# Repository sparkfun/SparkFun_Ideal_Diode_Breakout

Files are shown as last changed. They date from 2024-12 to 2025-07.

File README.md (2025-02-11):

SparkFun Ideal Diode Breakout
========================================

SparkFun Ideal Diode Breakout (https://www.sparkfun.com/products/27925)

[*SparkFun Ideal Diode Breakout (COM-27925)*](https://www.sparkfun.com/products/27925)




Keep your project powered up during power supply hot-swaps with the SparkFun Ideal Diode Breakout. This compact (15.2mm x 12.7mm) breakout board features four channels and ground connections, providing reliable one-way voltage control. Ideal diodes minimize forward voltage drop, internal power dissipation, and reverse DC leakage current, making them perfect for dynamic power selection and switchover, over-voltage protection, and projects requiring stable power input.

This breakout boasts impressive performance with a typical forward voltage drop as low as 8mV at 0.1A (20V input) and 62mV at 1A (20V input), ensuring efficient power delivery. For higher current applications, the forward voltage drop is typically 275mV at 4A (20V input). The typical on-resistance ranges from 69mΩ (20V, 4A) to 260mΩ (1.8V, 0.1A), depending on the input voltage and current. Reverse leakage current is minimal, ranging from -50µA to -560µA depending on reverse voltage and again on the input voltage.

Repository Contents
-------------------

* **/Hardware** - KiCAD design files (.brd, .sch)
* **/Documents** - Files related to the hardware on the board
* **/docs** - Hookup guide files

Documentation
--------------
* **[Hookup Guide](https://docs.sparkfun.com/SparkFun_Ideal_Diode_Breakout)** - Basic hookup guide for the SparkFun Ideal Diode Breakout

License Information
-------------------

This product is _**open source**_! 

Please review the LICENSE.md file for license information. 

If you have any questions or concerns on licensing, please contact technical support on our [SparkFun forums](https://forum.sparkfun.com/viewforum.php?f=152).

Distributed as-is; no warranty is given.

- Your friends at SparkFun.

_<COLLABORATION CREDIT>_

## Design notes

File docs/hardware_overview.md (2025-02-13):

---
icon: material/cog
---
## Overview

The SparkFun Ideal Diode Breakout uses four MOSFET P-CH SOT23 chips and four transistor arrays to provide four inputs and four outputs as well as a single common ground.  

## Typical Characteristics

We've gathered some data here to give you an idea of the typical characteristics and behavior of the diodes on this breakout. 

<div style="text-align: center;">
    <table>
        <tr>
            <td style="text-align: Left; border: solid 1px #cccccc;">Max forward current: 4.2A
            </td>
            <td style="text-align: center; border: solid 1px #cccccc;">This is based on the MOSFET current rating, which depends on various factors. Higher input voltge and higher forward current result in higher gate voltage, which reduces the drain-source resistance, which reduces heat dissipation, allowing for higher current before failure of MOSFET. 4.2A continuous should be achievable with VIN=5V and 25C ambient temperature. See MOSFET dtasheet for more details.
            </td>
        </tr>
        <tr>        
            <td style="text-align: Left; border: solid 1px #cccccc;">Breakdown voltage: -9.3V
            </td>
            <td style="text-align: center; border: solid 1px #cccccc;">The base-emitter path of the BJTs is effectively a diode, which exhibits breakdown behavior with a large reverse voltage. The BJT datasheet rates this as byeond -5V, however testing shows it occurs closer to -9V. The -9.3V rating of the ideal diode circuit includes the forward voltage drop of the other BJT's base-emitter path. Larger reverse voltages can be tolerated, however this can lead to significant heat and eventually failure of the BJT, so larger reverse voltages (<-10V) should only be applied briefly.
            </td>
        </tr>
        <tr>            
            <td style="text-align: Left; border: solid 1px #cccccc;">Max input voltage: 20V
            </td>   
            <td style="text-align: center; border: solid 1px #cccccc;">The MOSFET gate is pulled down when the ideal diode circuit operates in the forward region. This behavior is analog, so a higher input voltage and higher forward current brings the gate voltage closer to GND. The MOSFET datasheet only rates the gate-source voltage at 8V max, however testing has shown it can tolerate up to 20V before immediate failure, which is the motivation for the max input voltage rating of the ideal diode circuit. Extended operation with the gate-source voltage beyond 8V may result in degradation or failure.
            </td>
        </tr>
        <tr>            
            <td style="text-align: Left; border: solid 1px #cccccc;">Min input voltage: 1V-1.8V
            </td>   
            <td style="text-align: center; border: solid 1px #cccccc;">The threshold gate-source voltage of the MOSFET is typically 0.5V-0.9V according to the datasheet. The gate can only go as low as GND, which is the motivation for the 1V minimum. However the gate does not get pulled all the way to GND, so a low input voltage (1.8V and lower) results in a higher drain-source resistance. This can result in a higher forward voltage drop, and significantly more heating of the MOSFET with high current. Extended operation at low input voltage and high current could cause the MOSFET to fail.
            </td>
        </tr>
    </table>
</div>

Some initial testing gives us the following data. We've listed some of the basics; full information, including raw data and further graphs can be [found here](https://docs.google.com/spreadsheets/d/10VnG3ES4PncXXFxEykBQ4V_JlhlVdun92eYzSfNOVCA/edit?usp=sharing).

<figure markdown>
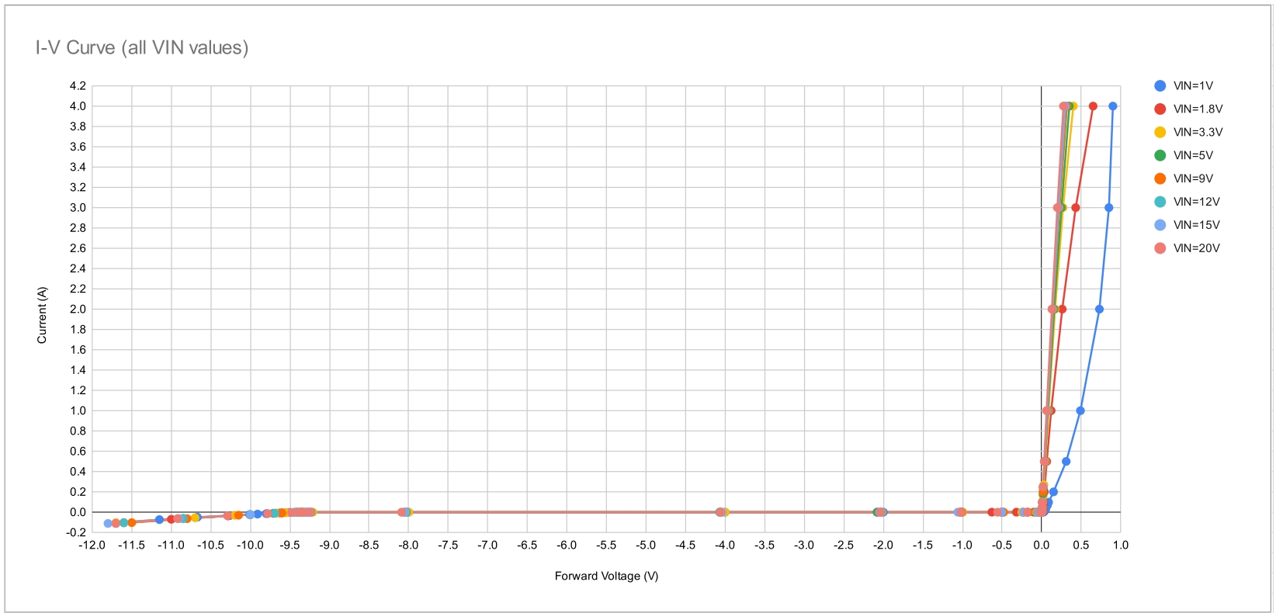
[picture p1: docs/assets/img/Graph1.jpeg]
Functional Graph 1

<figcaption markdown>Overall Current/Voltage Curve (Linear Scale)</figcaption>
</figure>

<figure markdown>
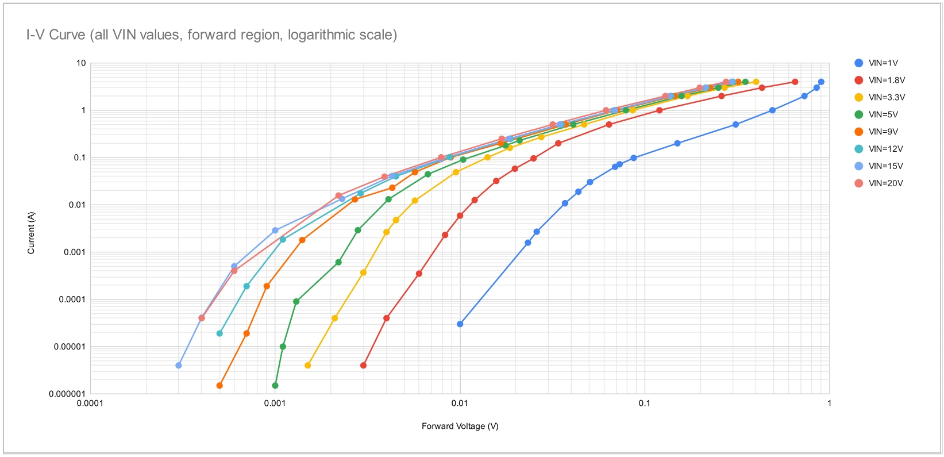
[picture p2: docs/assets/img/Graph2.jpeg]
Functional Graph 2

<figcaption markdown>Positive Region (Logarithmic Scale)</figcaption>
</figure>

<figure markdown>
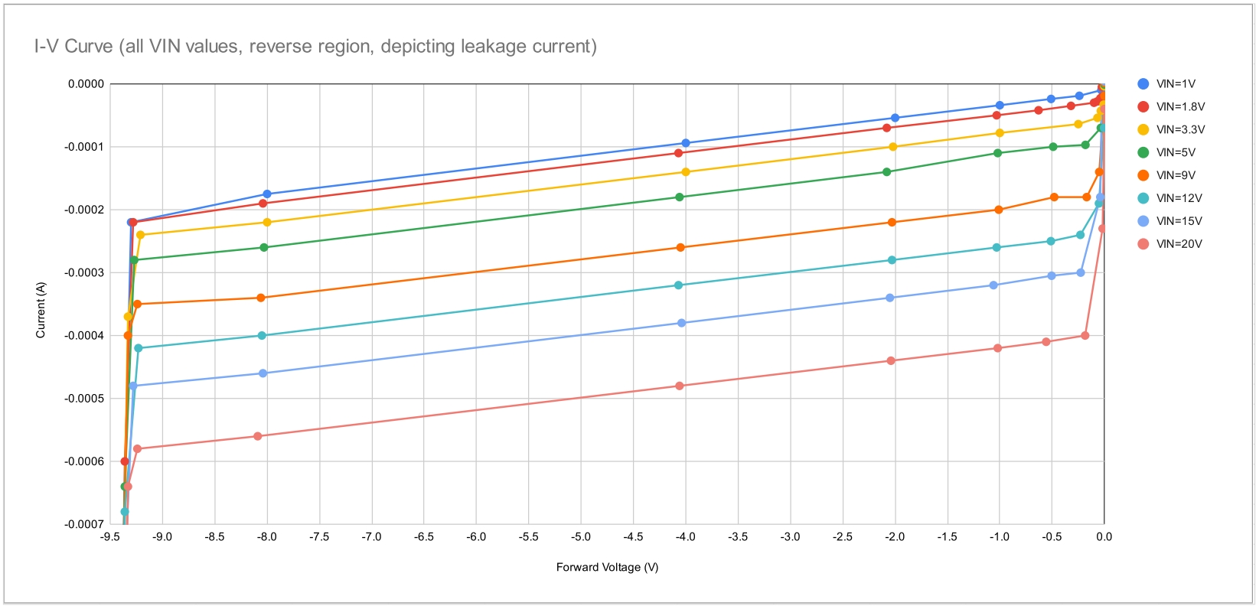
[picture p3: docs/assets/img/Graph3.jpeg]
Functional Graph 3

<figcaption markdown>Leakage Current</figcaption>
</figure>

<figure markdown>
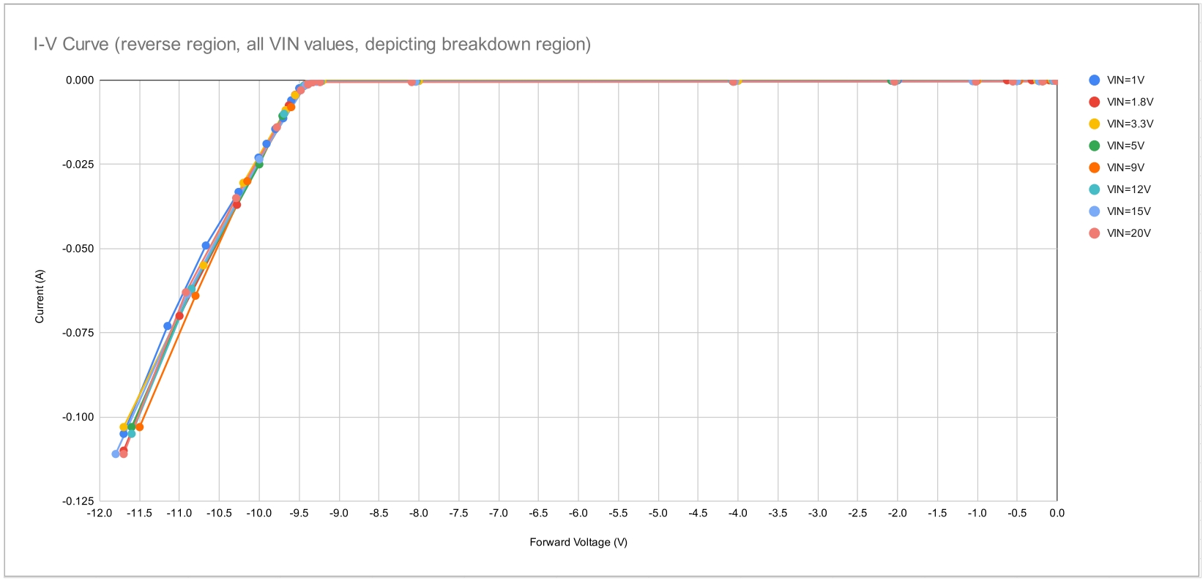
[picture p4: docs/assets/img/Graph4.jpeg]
Functional Graph 4

<figcaption markdown>Breakdown Voltage Behavior</figcaption>
</figure>

### 3D Model

A 3D model of the board and components was exported to a STEP file using KiCad.

<script type="module" src="https://ajax.googleapis.com/ajax/libs/model-viewer/3.5.0/model-viewer.min.js"></script>

<center>
    <model-viewer src="../assets/3d_model/SparkFun_Ideal_Diode_Breakout_3d_model.glb" camera-controls poster="../assets/3d_model/SparkFun_Ideal_Diode_Breakout_3d_model.png" environment-image="legacy" shadow-intensity="1.58" exposure="0.64" shadow-softness="0.24" tone-mapping="neutral" camera-orbit="-46.67deg 57.14deg 153.3m" field-of-view="30deg" style="width: 750px; height: 500px;">
    </model-viewer>
</center>
<br />
<div style="text-align: center">
    <a href="../assets/3d_model/SparkFun_Ideal_Diode_Breakout_3d_model.step" target="stp_file" class="md-button">Click Here for the STEP File</a>
</div>

### Board Dimensions

The board measures 15.2mm x 12.7mm(0.5 x 0.6 inches). 

<figure markdown>
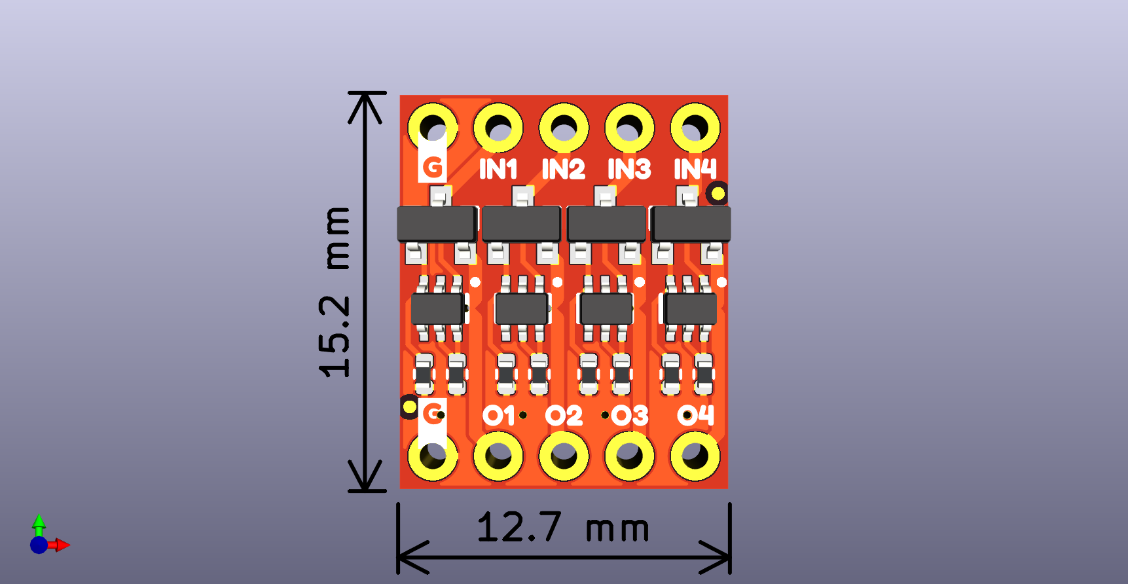
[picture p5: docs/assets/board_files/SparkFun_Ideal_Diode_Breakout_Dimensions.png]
Board Dimensions are 15.2mm by 12.7mm

<figcaption markdown>Board Dimensions</figcaption>
</figure>

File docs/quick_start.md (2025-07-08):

---
icon: material/run-fast
hide: toc
---

<div class="grid cards desc" markdown>

-    <a href="https://www.sparkfun.com/products/27925">
    **SparkFun Ideal Diode Breakout**<br>
    **SKU:** COM-27925

    ---

    <figure markdown>
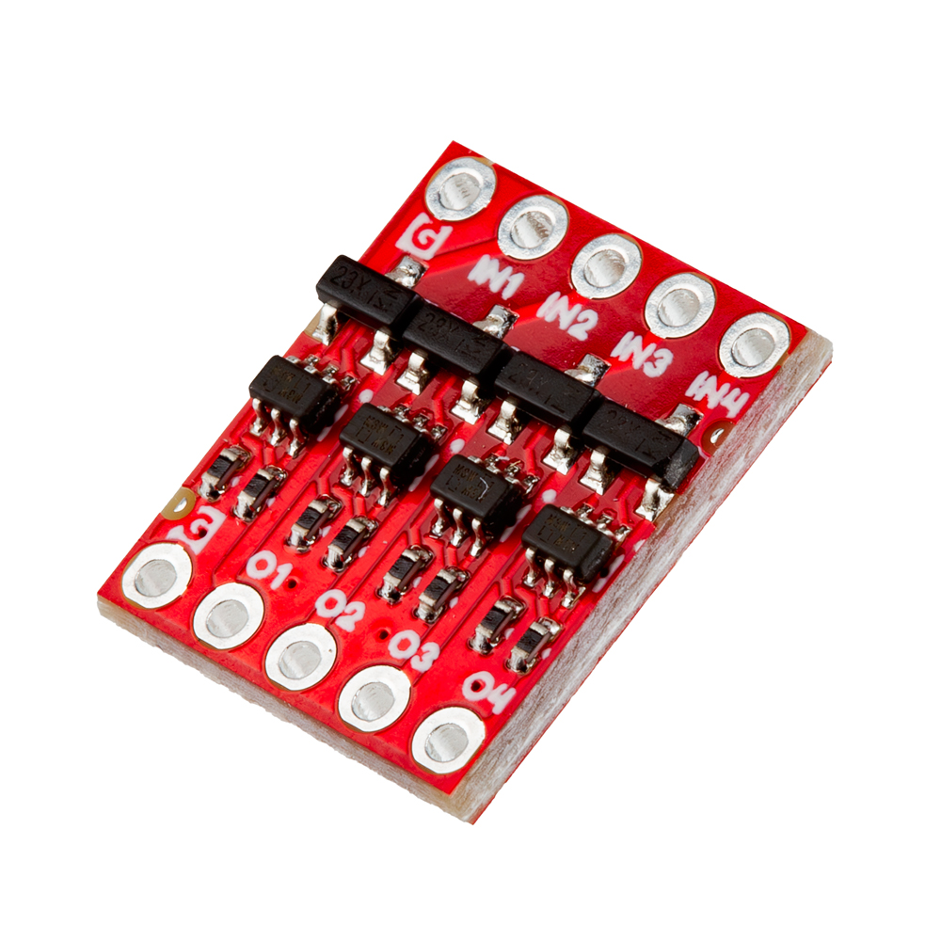
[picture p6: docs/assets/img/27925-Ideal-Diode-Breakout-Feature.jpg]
Product Thumbnail
    
    </figure></a>

-    Keep your project powered up during power supply hot-swaps with the SparkFun Ideal Diode Breakout. This compact (15.2mm x 12.7mm) breakout board features four channels and ground connections, providing reliable one-way voltage control. Ideal diodes minimize forward voltage drop, internal power dissipation, and reverse DC leakage current, making them perfect for dynamic power selection and switchover, over-voltage protection, and projects requiring stable power input.

    This breakout boasts impressive performance with a typical forward voltage drop as low as 8mV at 0.1A (20V input) and 62mV at 1A (20V input), ensuring efficient power delivery. For higher current applications, the forward voltage drop is typically 275mV at 4A (20V input). The typical on-resistance ranges from 69mΩ (20V, 4A) to 260mΩ (1.8V, 0.1A), depending on the input voltage and current. Reverse leakage current is minimal, ranging from -50µA to -560µA depending on reverse voltage and again on the input voltage.

    <center>
    [Purchase from SparkFun :fontawesome-solid-cart-plus:{ .heart }](https://www.sparkfun.com/products/27925){ .md-button .md-button--primary }
    </center>

</div>

## Hooking Up the Breakout

Hooking up the SparkFun Ideal Diode Breakout is fairly straightforward. Power inputs go through two separate input circuits but have a common ground. A quick example shows consistent current being supplied to the board from two separate power supplies. Note that as one power supply decreases, the other draw increases to provide consistent voltage: 

<figure markdown>
Hot Swapping Power Supply
<figcaption markdown>Hot Swapping a Power Supply to a Motor</figcaption>
</figure>

Hookup looks something like the following: 

<figure markdown>
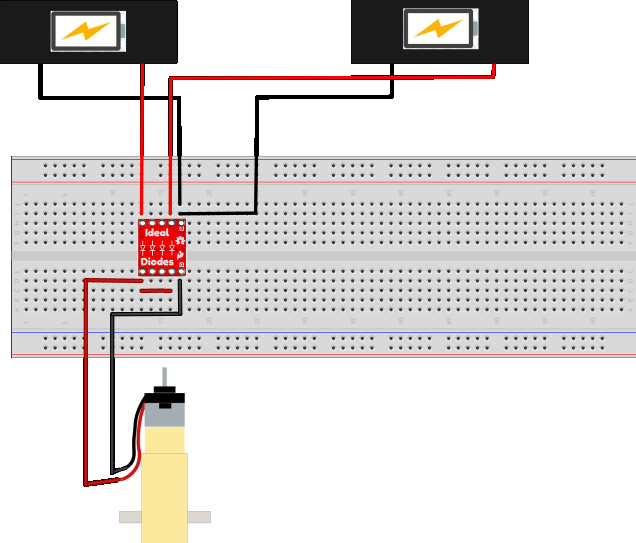
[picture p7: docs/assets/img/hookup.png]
Hot Swapping Power Supply

<figcaption markdown>Hot Swapping a Power Supply to a Motor</figcaption>
</figure>

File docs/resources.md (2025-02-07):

For more information, check out the resources below:

* [Ideal Diode Characteristics (PDF)](../assets/board_files/IdealDiodeCharacteristics-Graphs.pdf)
* [Schematic (PDF)](../assets/board_files/27925_SparkFun_Ideal_Diode_Breakout_Schematic.pdf)
* [KiCad Files (ZIP)](../assets/board_files/27925_SparkFun_Ideal_Diode_Breakout_KiCADFiles.zip)
* [3D Model (STEP)](../assets/3d_model/SparkFun_Ideal_Diode_Breakout_3d_model.step)
* [Board Dimensions (PNG)](../assets/board_files/SparkFun_Ideal_Diode_Breakout_Dimensions.png)
* [GitHub Hardware Repo](https://github.com/sparkfun/SparkFun_Ideal_Diode_Breakout)

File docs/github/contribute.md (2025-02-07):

# Contribute: Help Fix our Mistake!
Spot something wrong? Feel free to contribute our open-source design and documentation. 

## Improve our Documentation
All of this documentation can be modified by you! Please help us make it better.

* These pages are contained in the [`docs` folder of the SparkFun Ideal Diode Breakout repository](https://github.com/sparkfun/SparkFun_Ideal_Diode_Breakout/tree/main/docs).

### Submit a Correction
1. Fork this repo
2. Add your corrections or improvements to the markdown file
3. File a pull request with your changes, and enjoy making the ~~words~~ ~~worlds~~ world a better place.
    * Once received, the documentation specialist will automatically be notified.
    * We will review your suggested improvements to make sure they are correct and fit within our documentation standards.

## Improve our Hardware Design
All of our designs are open-source! Please help us make it better.

* Our board design files are contained in the [`Hardware` folder of the SparkFun Ideal Diode Breakout repository](https://github.com/sparkfun/SparkFun_Ideal_Diode_Breakout/tree/main/Hardware).

### Submit a Design Improvement
1. Fork this repo
2. Add your design improvements
3. File a pull request with your changes, and enjoy making the ~~words~~ ~~worlds~~ world a better place.
    * Once received, the engineer in charge of the original design will automatically be notified.
    * We will review your suggested improvements, if they are within our board design standards and meet our product design requirements, we will flag these changes for our next board revision. *(Please note, that even if your suggestion is accepted, these changes may not be immediate. We may have to cycle through our current product inventory first.)*

## Contributors
Let's provided some recognition to the contributors for this project!

GitHub Contributors Image
<br>


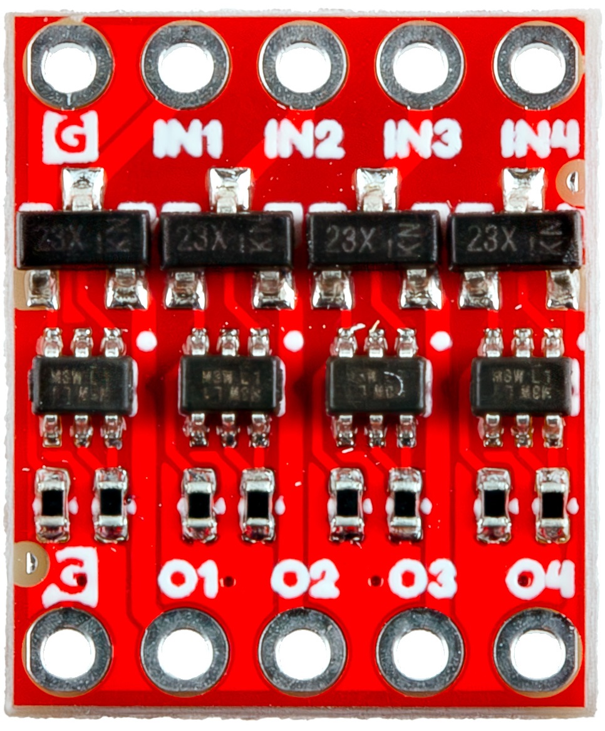
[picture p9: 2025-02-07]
docs/assets/img/27925-Ideal-Diode-Breakout-Front-high-res.jpg

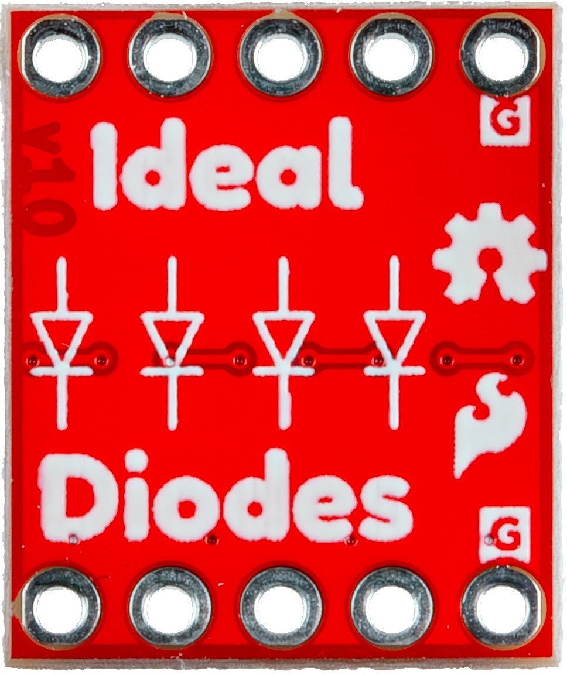
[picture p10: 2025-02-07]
docs/assets/img/27925-Ideal-Diode-Breakout-Back-high-res.jpg

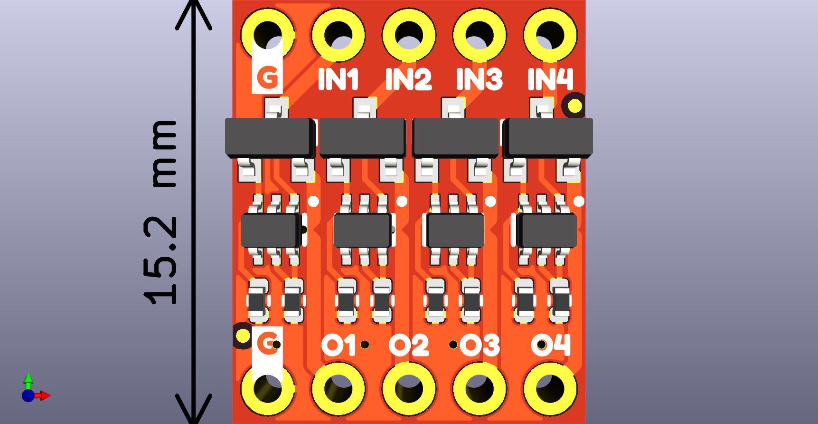
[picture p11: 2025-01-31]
docs/assets/3d_model/SparkFun_Ideal_Diode_Breakout_3d_model.png

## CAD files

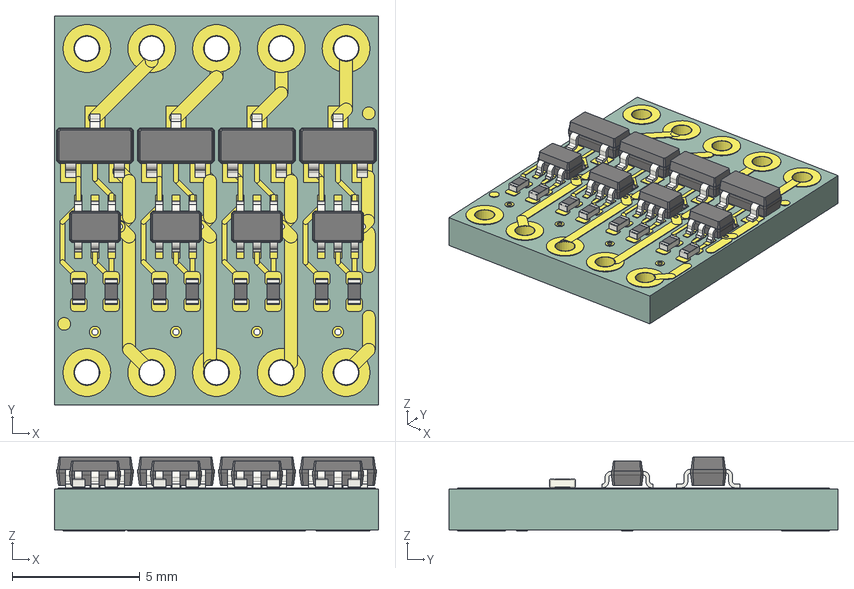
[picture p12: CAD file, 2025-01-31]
docs/assets/3d_model/SparkFun_Ideal_Diode_Breakout_3d_model.step
12.7 x 15.2 x 2.88 mm
R_0402_1005Metric x 8
SOT_363_SC_70_6 x 4
SOT_23 x 4
SparkFun_Ideal_Diode_Breakout_track_1
SparkFun_Ideal_Diode_Breakout_track_2
SparkFun_Ideal_Diode_Breakout_track_3
SparkFun_Ideal_Diode_Breakout_track_4
SparkFun_Ideal_Diode_Breakout_track_5
SparkFun_Ideal_Diode_Breakout_track_6
SparkFun_Ideal_Diode_Breakout_track_7
SparkFun_Ideal_Diode_Breakout_track_8
SparkFun_Ideal_Diode_Breakout_track_9
SparkFun_Ideal_Diode_Breakout_track_10
SparkFun_Ideal_Diode_Breakout_track_11
SparkFun_Ideal_Diode_Breakout_track_12
SparkFun_Ideal_Diode_Breakout_track_13
SparkFun_Ideal_Diode_Breakout_track_14
SparkFun_Ideal_Diode_Breakout_track_15
SparkFun_Ideal_Diode_Breakout_track_16
SparkFun_Ideal_Diode_Breakout_track_17
SparkFun_Ideal_Diode_Breakout_track_18
SparkFun_Ideal_Diode_Breakout_track_19
SparkFun_Ideal_Diode_Breakout_track_20
SparkFun_Ideal_Diode_Breakout_track_21
SparkFun_Ideal_Diode_Breakout_track_22
SparkFun_Ideal_Diode_Breakout_track_23
SparkFun_Ideal_Diode_Breakout_track_24
SparkFun_Ideal_Diode_Breakout_track_25
SparkFun_Ideal_Diode_Breakout_track_26
SparkFun_Ideal_Diode_Breakout_track_27
SparkFun_Ideal_Diode_Breakout_track_28
SparkFun_Ideal_Diode_Breakout_track_29
SparkFun_Ideal_Diode_Breakout_track_30
SparkFun_Ideal_Diode_Breakout_track_31
SparkFun_Ideal_Diode_Breakout_track_32
SparkFun_Ideal_Diode_Breakout_track_33
SparkFun_Ideal_Diode_Breakout_track_34
SparkFun_Ideal_Diode_Breakout_track_35
SparkFun_Ideal_Diode_Breakout_track_36
SparkFun_Ideal_Diode_Breakout_track_37
SparkFun_Ideal_Diode_Breakout_track_38
SparkFun_Ideal_Diode_Breakout_track_39
SparkFun_Ideal_Diode_Breakout_track_40
SparkFun_Ideal_Diode_Breakout_track_41
SparkFun_Ideal_Diode_Breakout_track_42
SparkFun_Ideal_Diode_Breakout_track_43
SparkFun_Ideal_Diode_Breakout_track_44
SparkFun_Ideal_Diode_Breakout_track_45
SparkFun_Ideal_Diode_Breakout_track_46
SparkFun_Ideal_Diode_Breakout_track_47
SparkFun_Ideal_Diode_Breakout_track_48
SparkFun_Ideal_Diode_Breakout_track_49
SparkFun_Ideal_Diode_Breakout_track_50
SparkFun_Ideal_Diode_Breakout_track_51
SparkFun_Ideal_Diode_Breakout_track_52
SparkFun_Ideal_Diode_Breakout_track_53
SparkFun_Ideal_Diode_Breakout_track_54
SparkFun_Ideal_Diode_Breakout_track_55
SparkFun_Ideal_Diode_Breakout_track_56
SparkFun_Ideal_Diode_Breakout_track_57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

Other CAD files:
Hardware/SparkFun_Ideal_Diode_Breakout.step

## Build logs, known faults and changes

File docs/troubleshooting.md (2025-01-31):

### General Troubleshooting Help

!!! note
    <span class="glyphicon glyphicon-question-sign" aria-hidden="true"></span>
        <strong> Not working as expected and need help? </strong> <br /><br />

    If you need technical assistance and more information on a product that is not working as you expected, we recommend heading on over to the <a href="https://www.sparkfun.com/technical_assistance">SparkFun Technical Assistance</a> page for some initial troubleshooting. <br /><br />

    <div style="text-align: center"><a href="https://www.sparkfun.com/technical_assistance" target="sfe_technical_assistance" class="md-button">SparkFun Technical Assistance Page</a></div>

    If you don't find what you need there, the <a href="https://community.sparkfun.com/">SparkFun Forums</a> are a great place to find and ask for help. If this is your first visit, you'll need to create a forum account to search product forums and post questions.<br /><br />

    <div style="text-align: center"><a href="https://community.sparkfun.com/" class="md-button md-button--primary">Log Into SparkFun Forums</a></div>

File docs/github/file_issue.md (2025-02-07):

# Did we make a mistake?

Spot something wrong? Please let us know. 

!!! attention
    This is not where customers should seek assistance on a product. If you require technical assistance or have questions about a product that is not working as expected, please head over to the [SparkFun Technical Assistance](https://www.sparkfun.com/technical_assistance) page for some initial troubleshooting.
    <center>
    [SparkFun Technical Assistance Page](https://www.sparkfun.com/technical_assistance){ .md-button .md-button--primary }
    </center>

    If you can't find what you need there, you'll need a [Forum Account](https://forum.sparkfun.com/ucp.php?mode=register) to search product forums and post questions.

## Discrepancies in the Documentation

All of this documentation can be modified by you! Please help us make it better.

* The documentation files for these pages are contained in the [`docs` folder of the SparkFun Ideal Diode Breakout repository](https://github.com/sparkfun/SparkFun_Ideal_Diode_Breakout/tree/main/docs).

### Spot something wrong?
If a section of the documentation is incorrect, please [open an issue](https://github.com/sparkfun/SparkFun_Ideal_Diode_Breakout/issues) and let us know.

### Do you have a suggested correction?
1. With a GitHub account, fork this repo
2. Add your correction(s) or improvement(s) to the markdown file(s)
3. File a pull request with your changes, and enjoy making the ~~words~~ ~~worlds~~ world a better place.
    * Once received, the documentation specialist will automatically be notified.
    * We will review your suggested improvement(s) to make sure they are correct and fit within our documentation standards.

## Problems in the Hardware Design

All of our designs are open-source! Please help us make it better.

* Our board design files are contained in the [`Hardware` folder of the SparkFun Ideal Diode Breakout repository](https://github.com/sparkfun/SparkFun_Ideal_Diode_Breakout/tree/main/Hardware).

### Does something not make sense?
If part of the design is confusing, please [open an issue](https://github.com/sparkfun/SparkFun_Ideal_Diode_Breakout/issues) and let us know.

### Did we forget to include an important function of the board?
* Please keep in mind that we may intentionally exclude certain functions of the board to meet our product design requirements. *(For example, our Qwiic Micro boards are intended to fit on a small board layout and only use I<sup>2</sup>C communication; therefore, we may not have the SPI and interrupt pins available for users.)*
* If part of the board's functionality is missing, please [open an issue](https://github.com/sparkfun/SparkFun Ideal Diode BreakoutSparkFun_Ideal_Diode_Breakout/issues) and file a feature request.

### Do you wish to contribute directly to improving the board design?
1. With a GitHub account, Fork this repo
2. Add your design improvement(s)
3. File a pull request with your changes, and enjoy making the ~~words~~ ~~worlds~~ world a better place.
    * Once received, the engineer in charge of the original design will automatically be notified.
    * We will review your suggested improvement(s), if they are within our board design standards and meet our product design requirements, we will flag these changes for our next board revision. *(Please note, that even if your suggestion is accepted, these changes may not be immediate. We may have to cycle through our current product inventory first.)*

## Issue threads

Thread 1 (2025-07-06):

Missing Wire in Hookup Guide

ckschanker, 2025-07-06:
In the circuit from the hookup guide, the wire connecting the two diodes on the load side is missing.

sfe-SparkFro, 2025-07-08:
Thanks for catching that, fixed in [95539c9](https://github.com/sparkfun/SparkFun_Ideal_Diode_Breakout/commit/95539c9539a251a59b586447ce8aa59600a3b0cf)!

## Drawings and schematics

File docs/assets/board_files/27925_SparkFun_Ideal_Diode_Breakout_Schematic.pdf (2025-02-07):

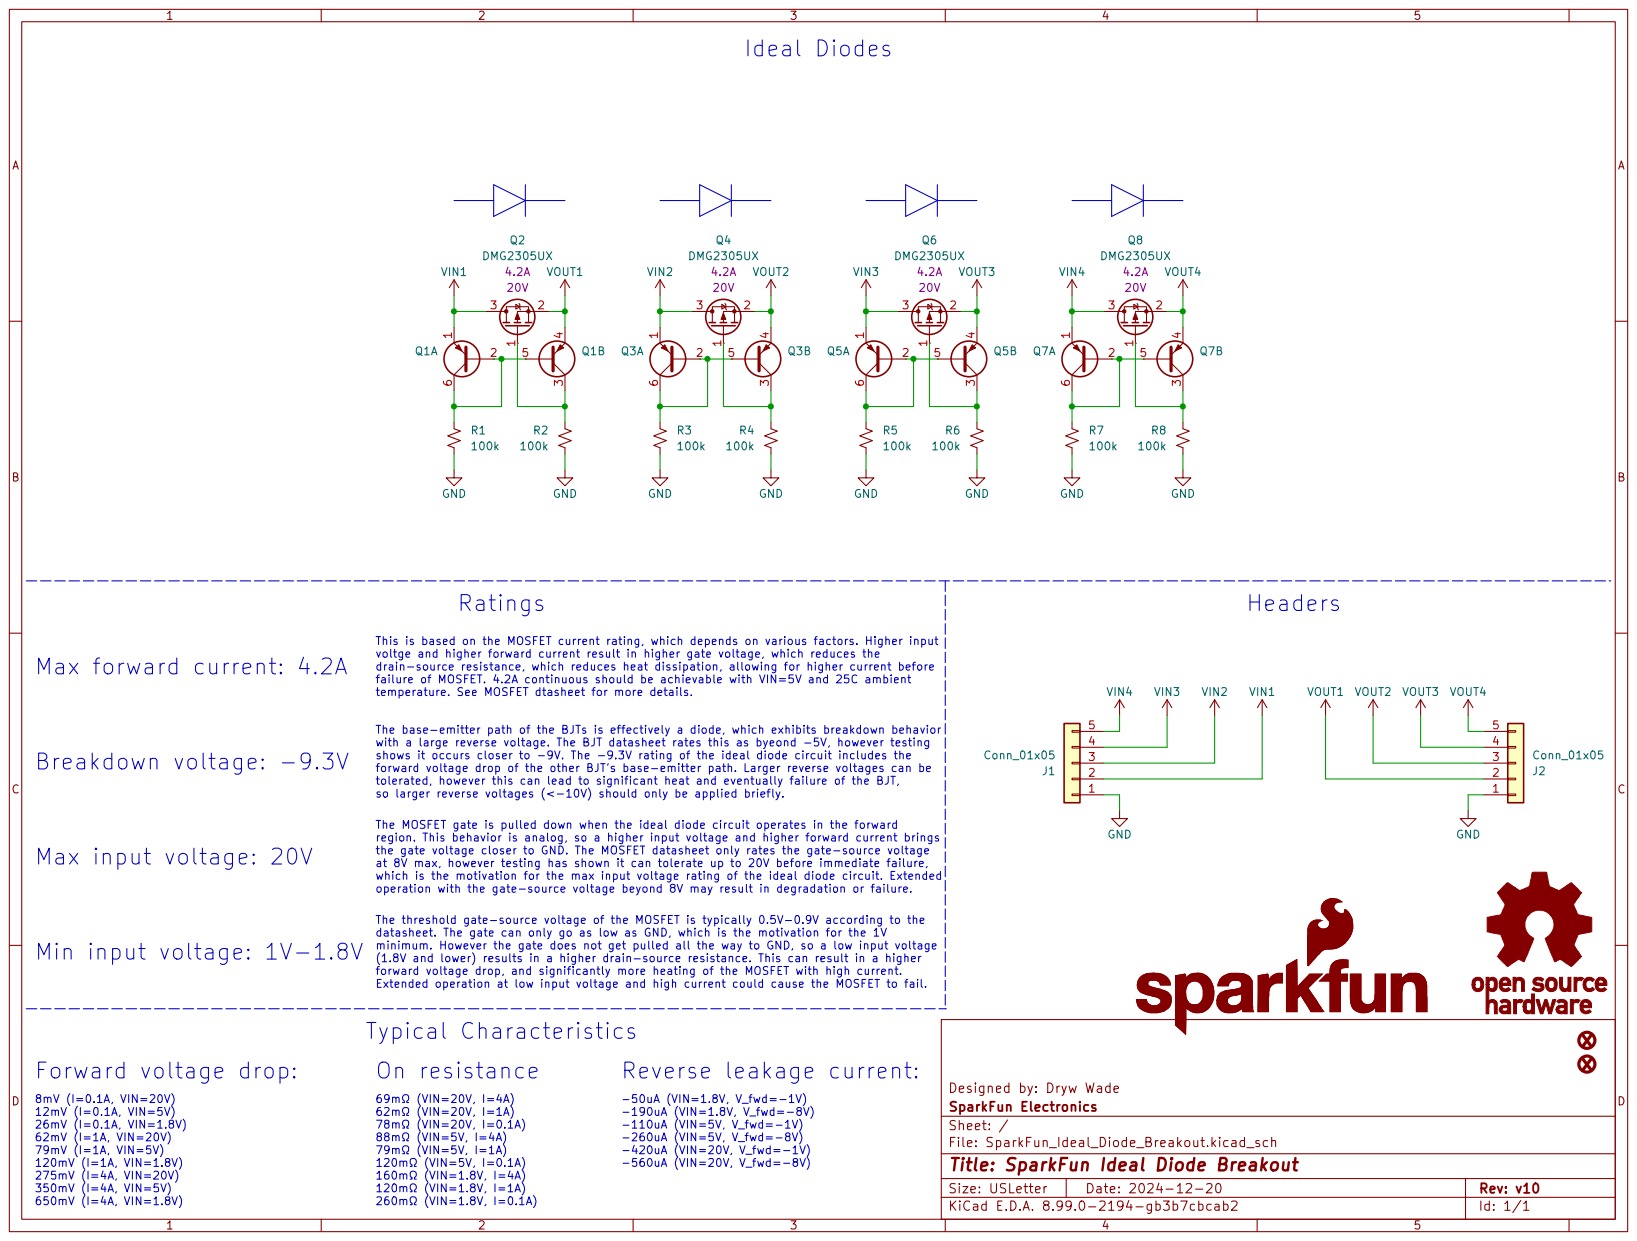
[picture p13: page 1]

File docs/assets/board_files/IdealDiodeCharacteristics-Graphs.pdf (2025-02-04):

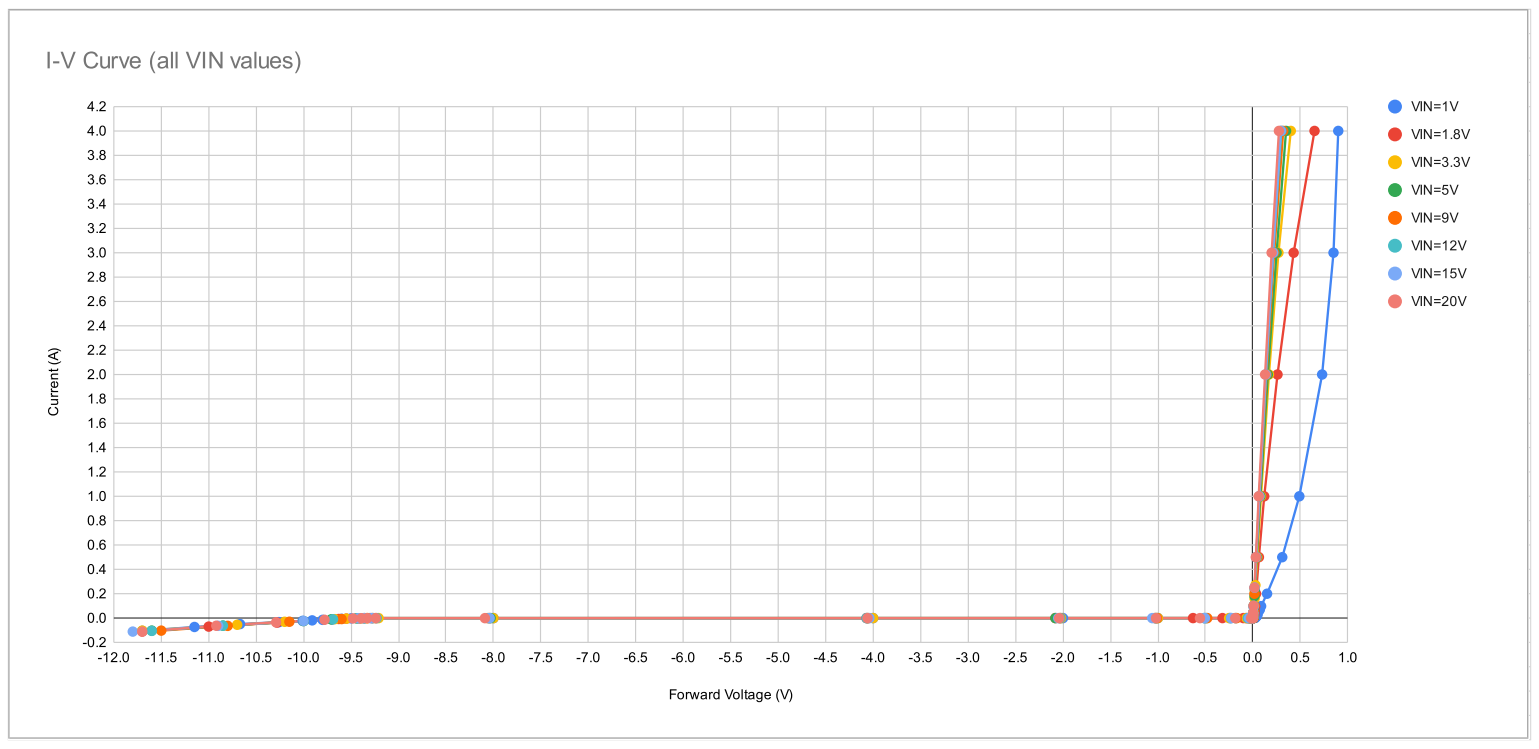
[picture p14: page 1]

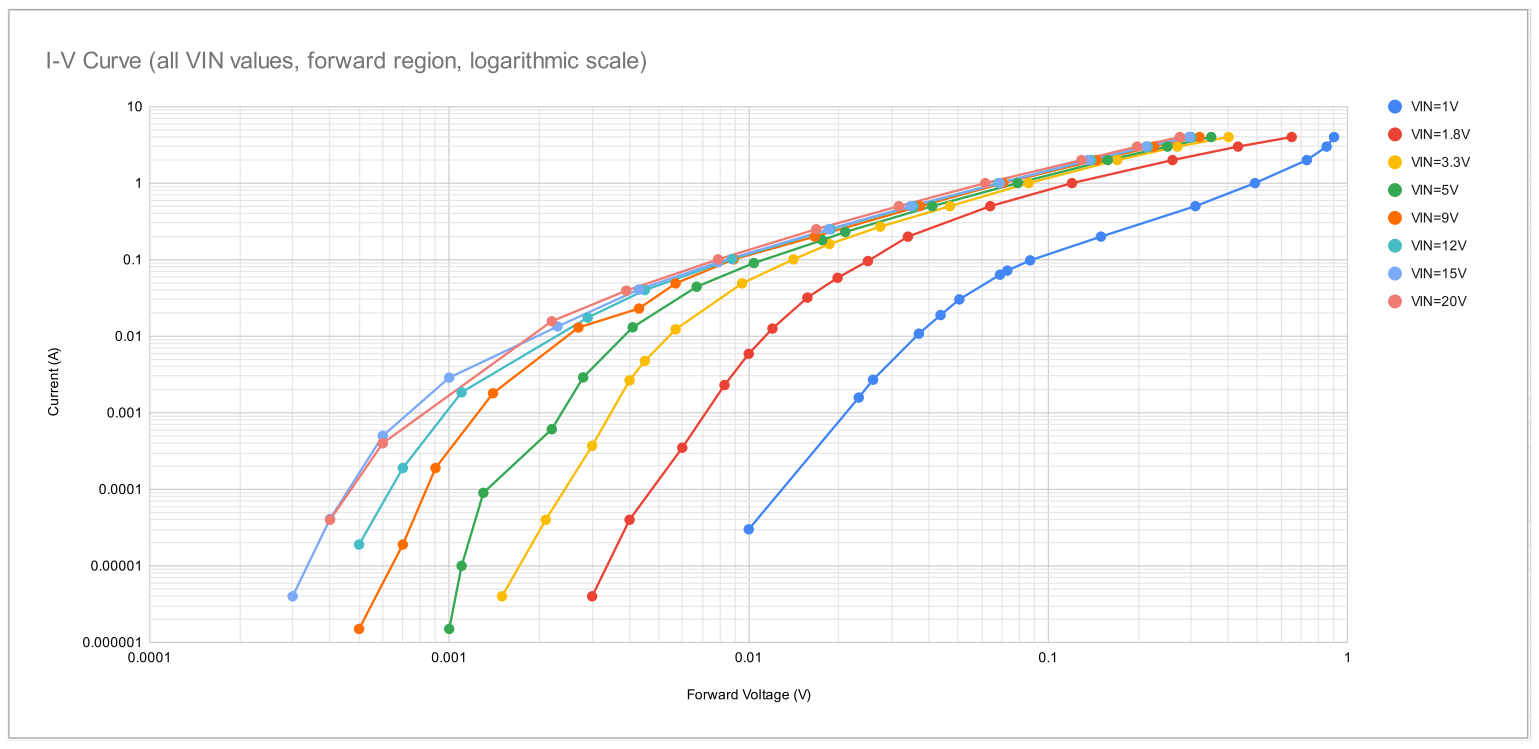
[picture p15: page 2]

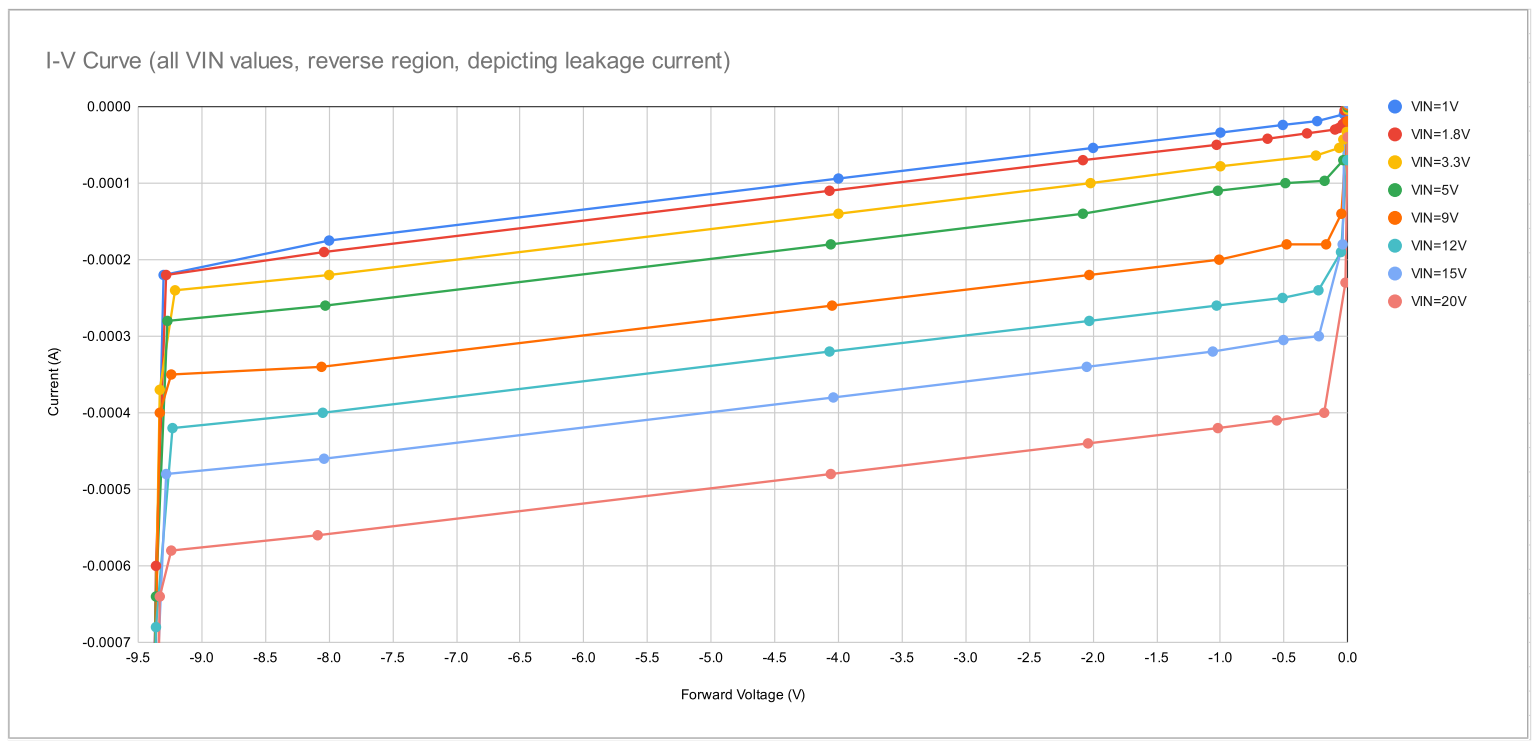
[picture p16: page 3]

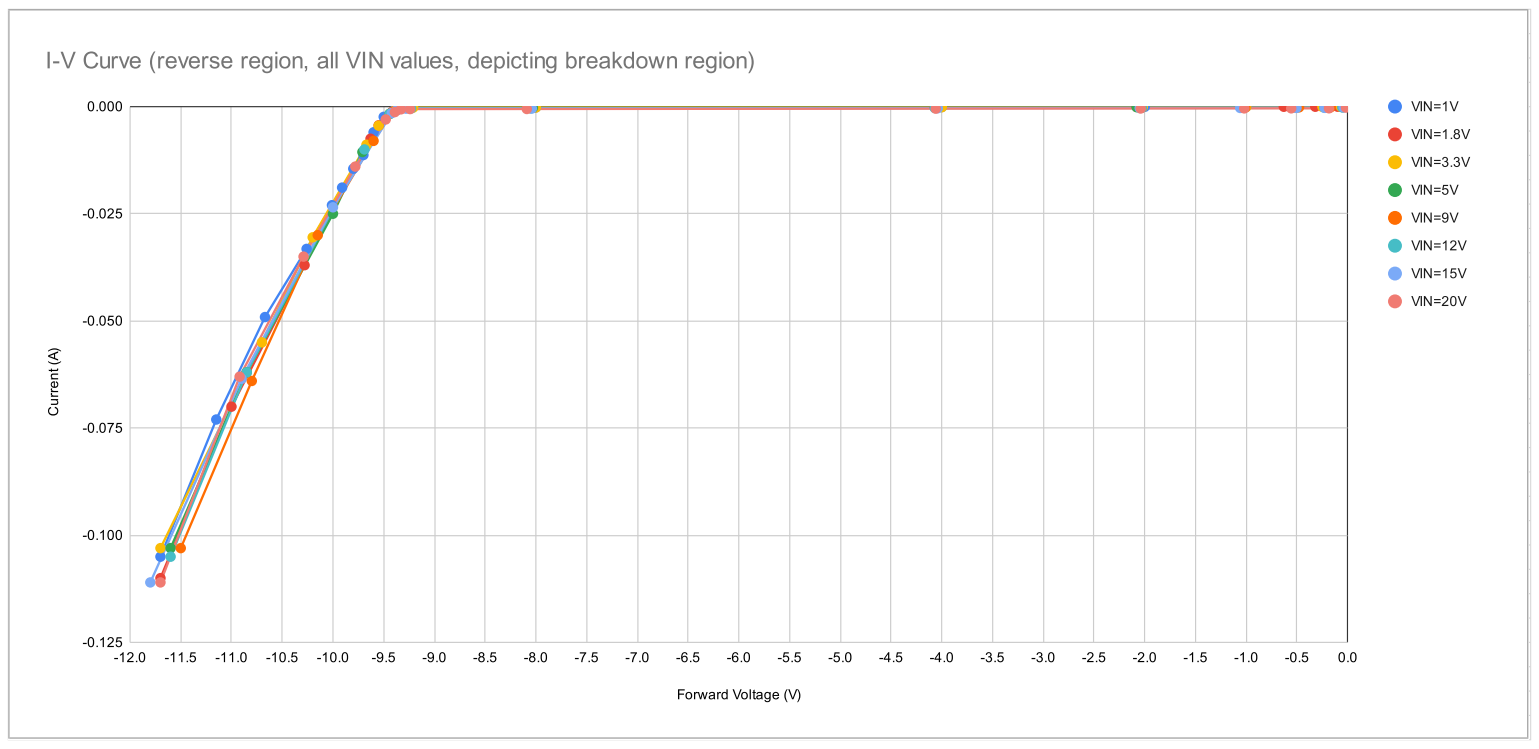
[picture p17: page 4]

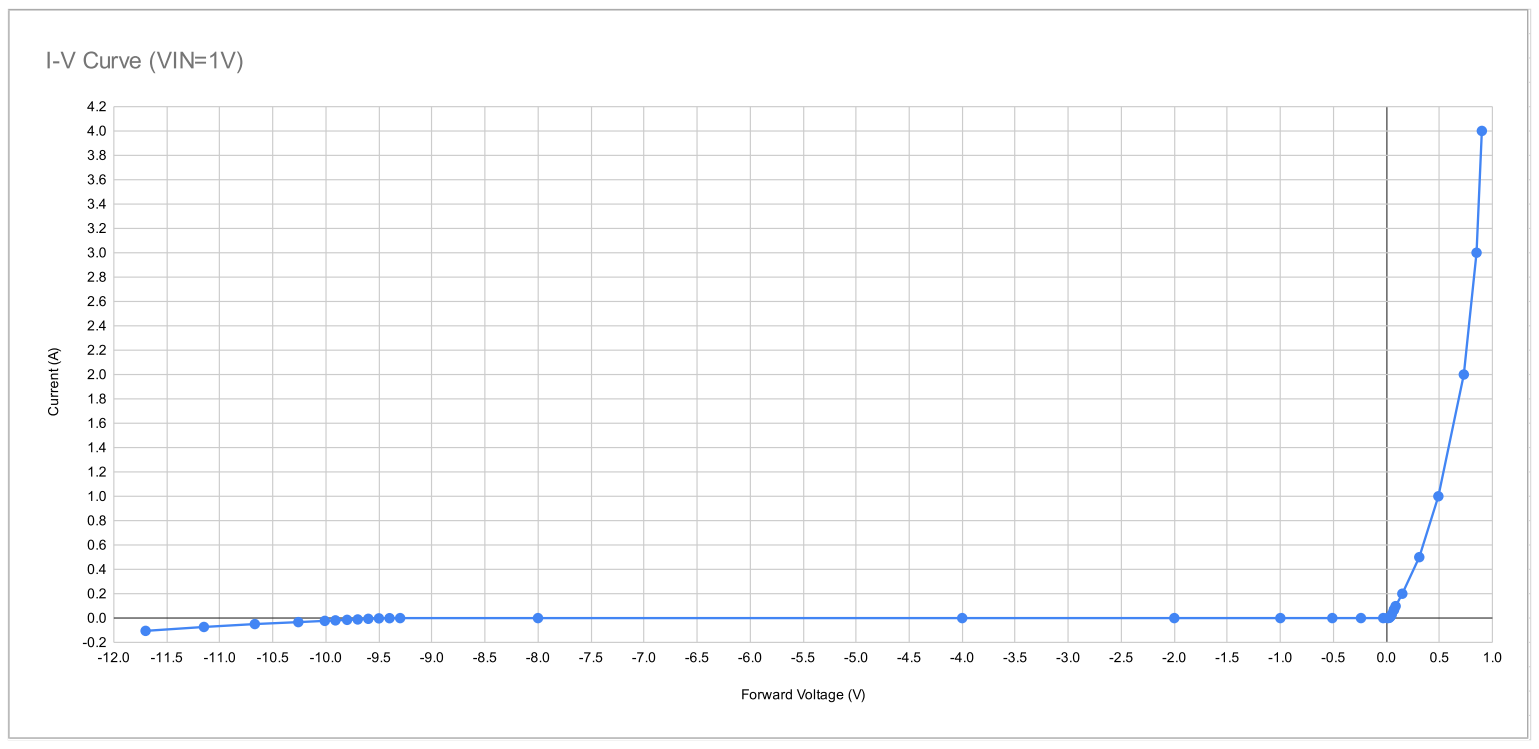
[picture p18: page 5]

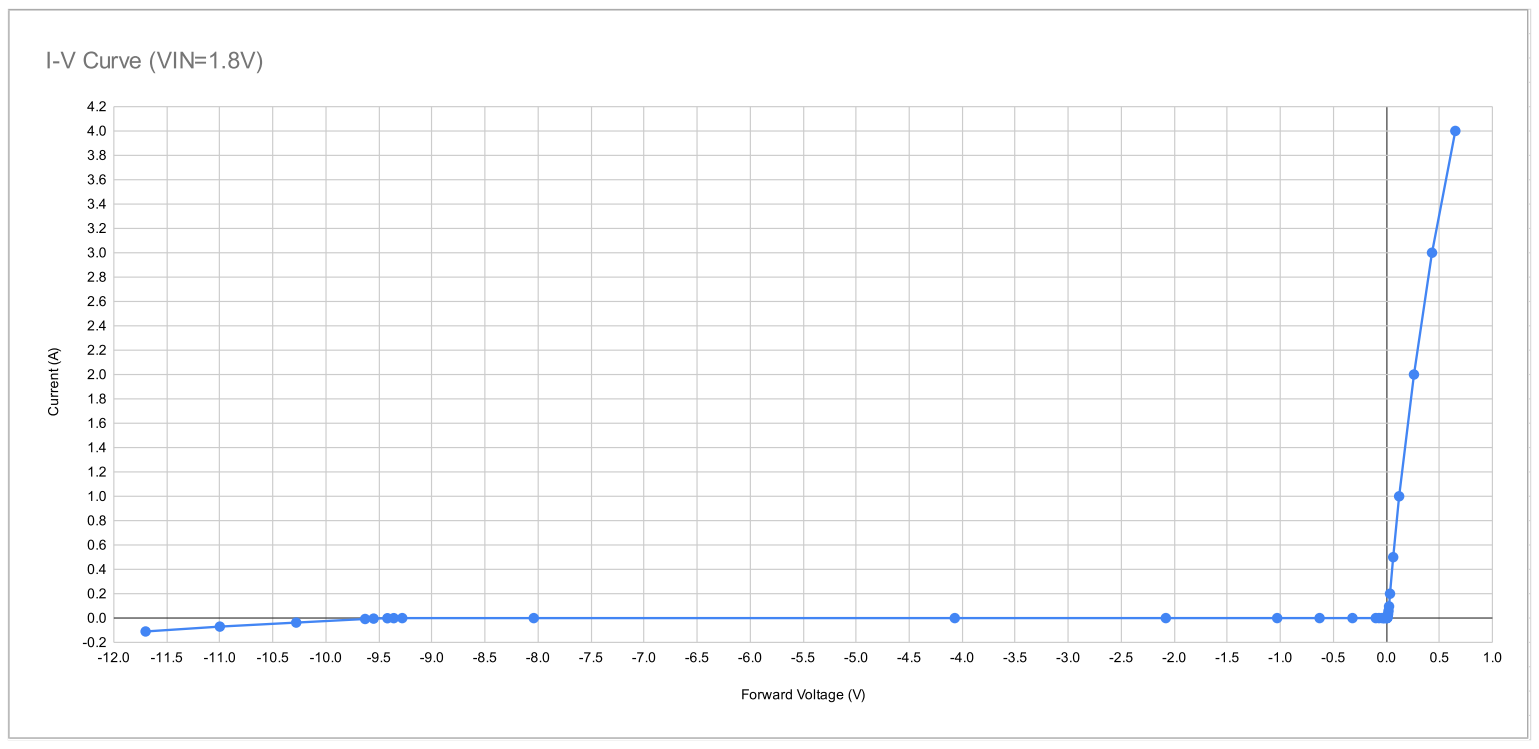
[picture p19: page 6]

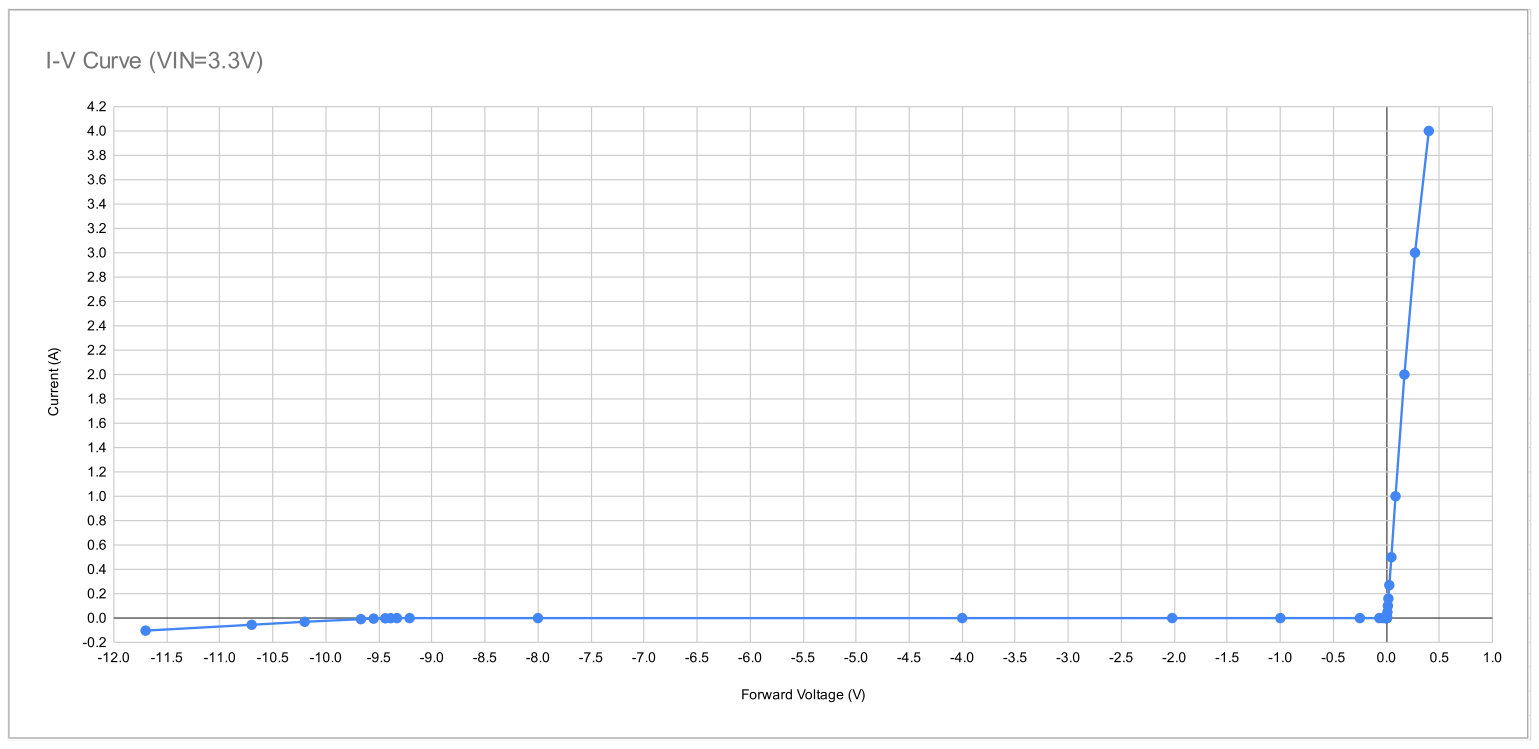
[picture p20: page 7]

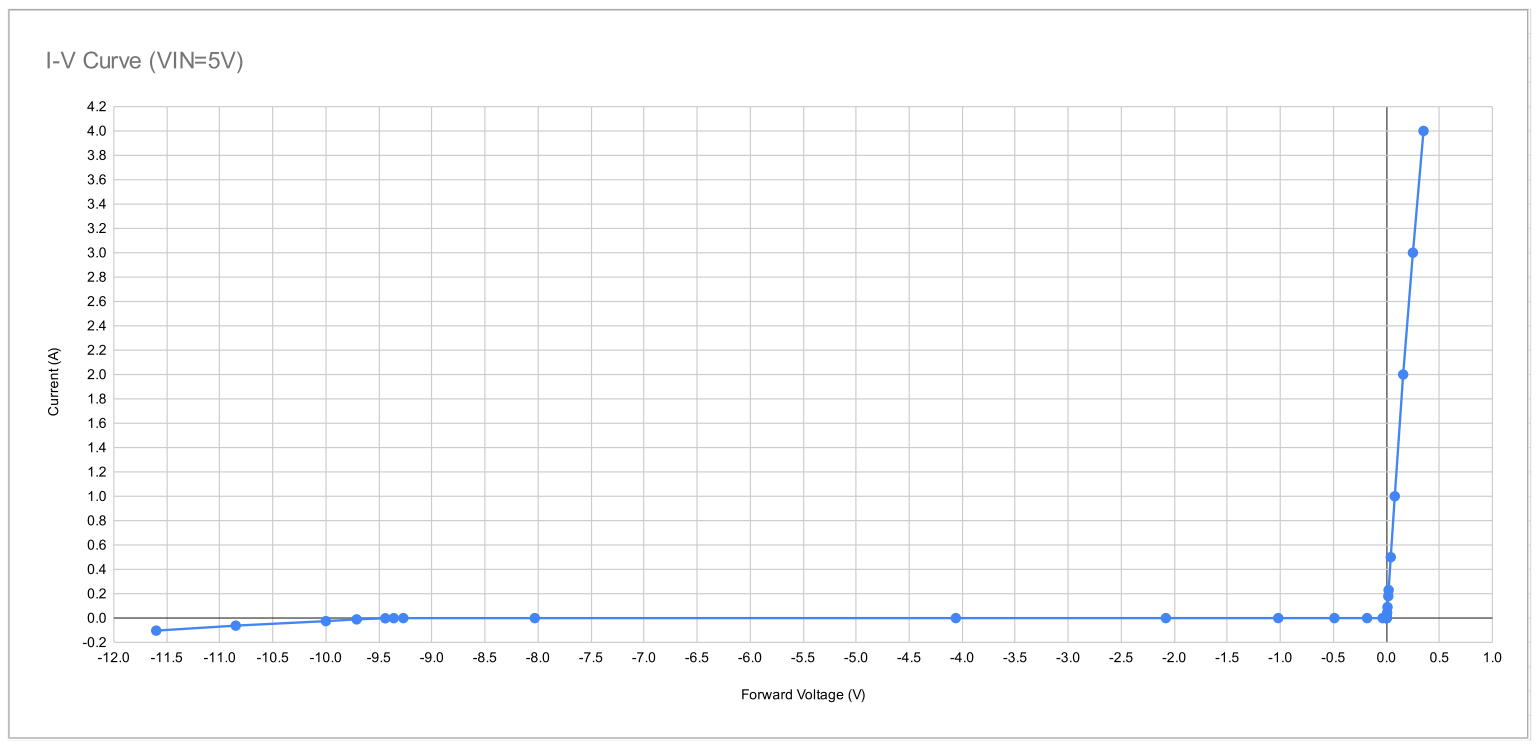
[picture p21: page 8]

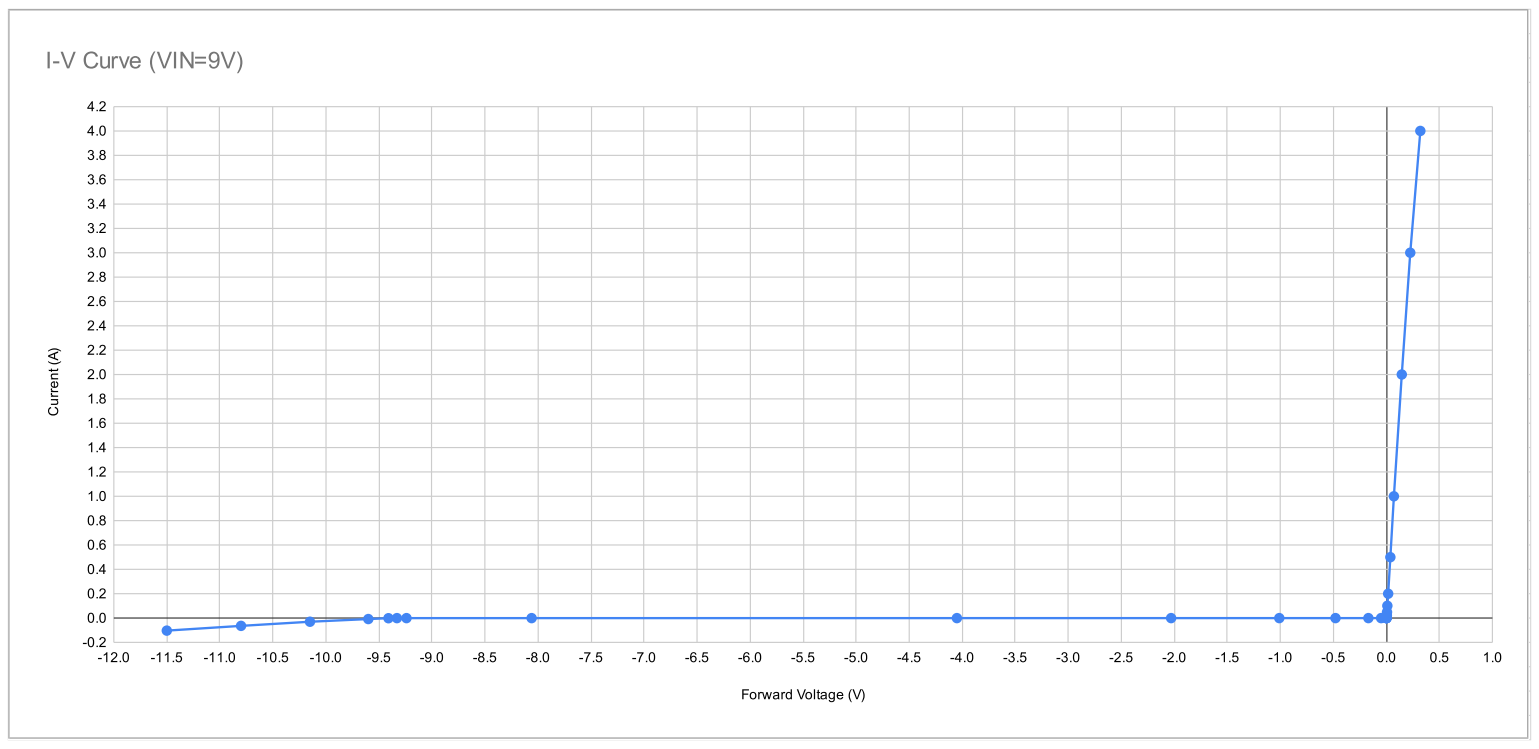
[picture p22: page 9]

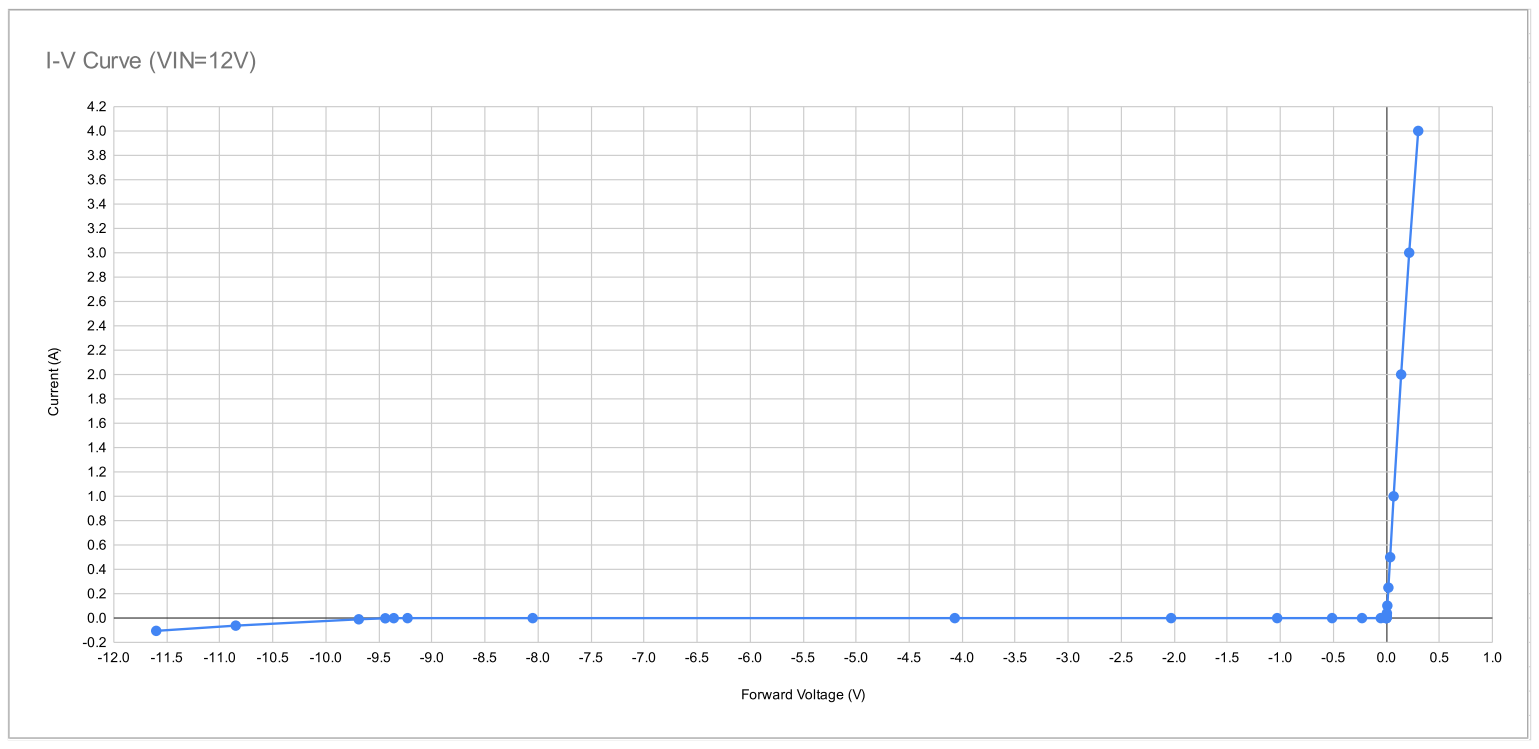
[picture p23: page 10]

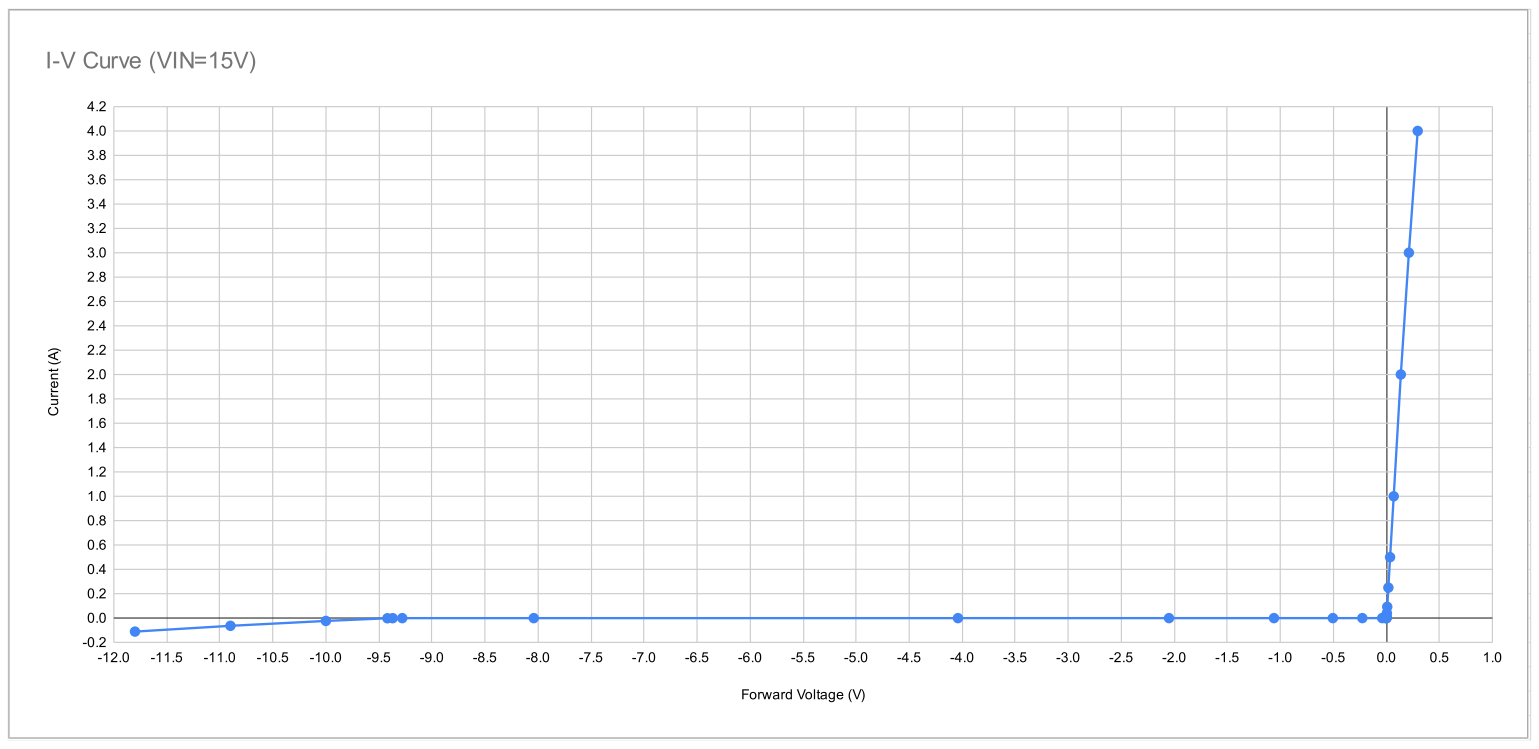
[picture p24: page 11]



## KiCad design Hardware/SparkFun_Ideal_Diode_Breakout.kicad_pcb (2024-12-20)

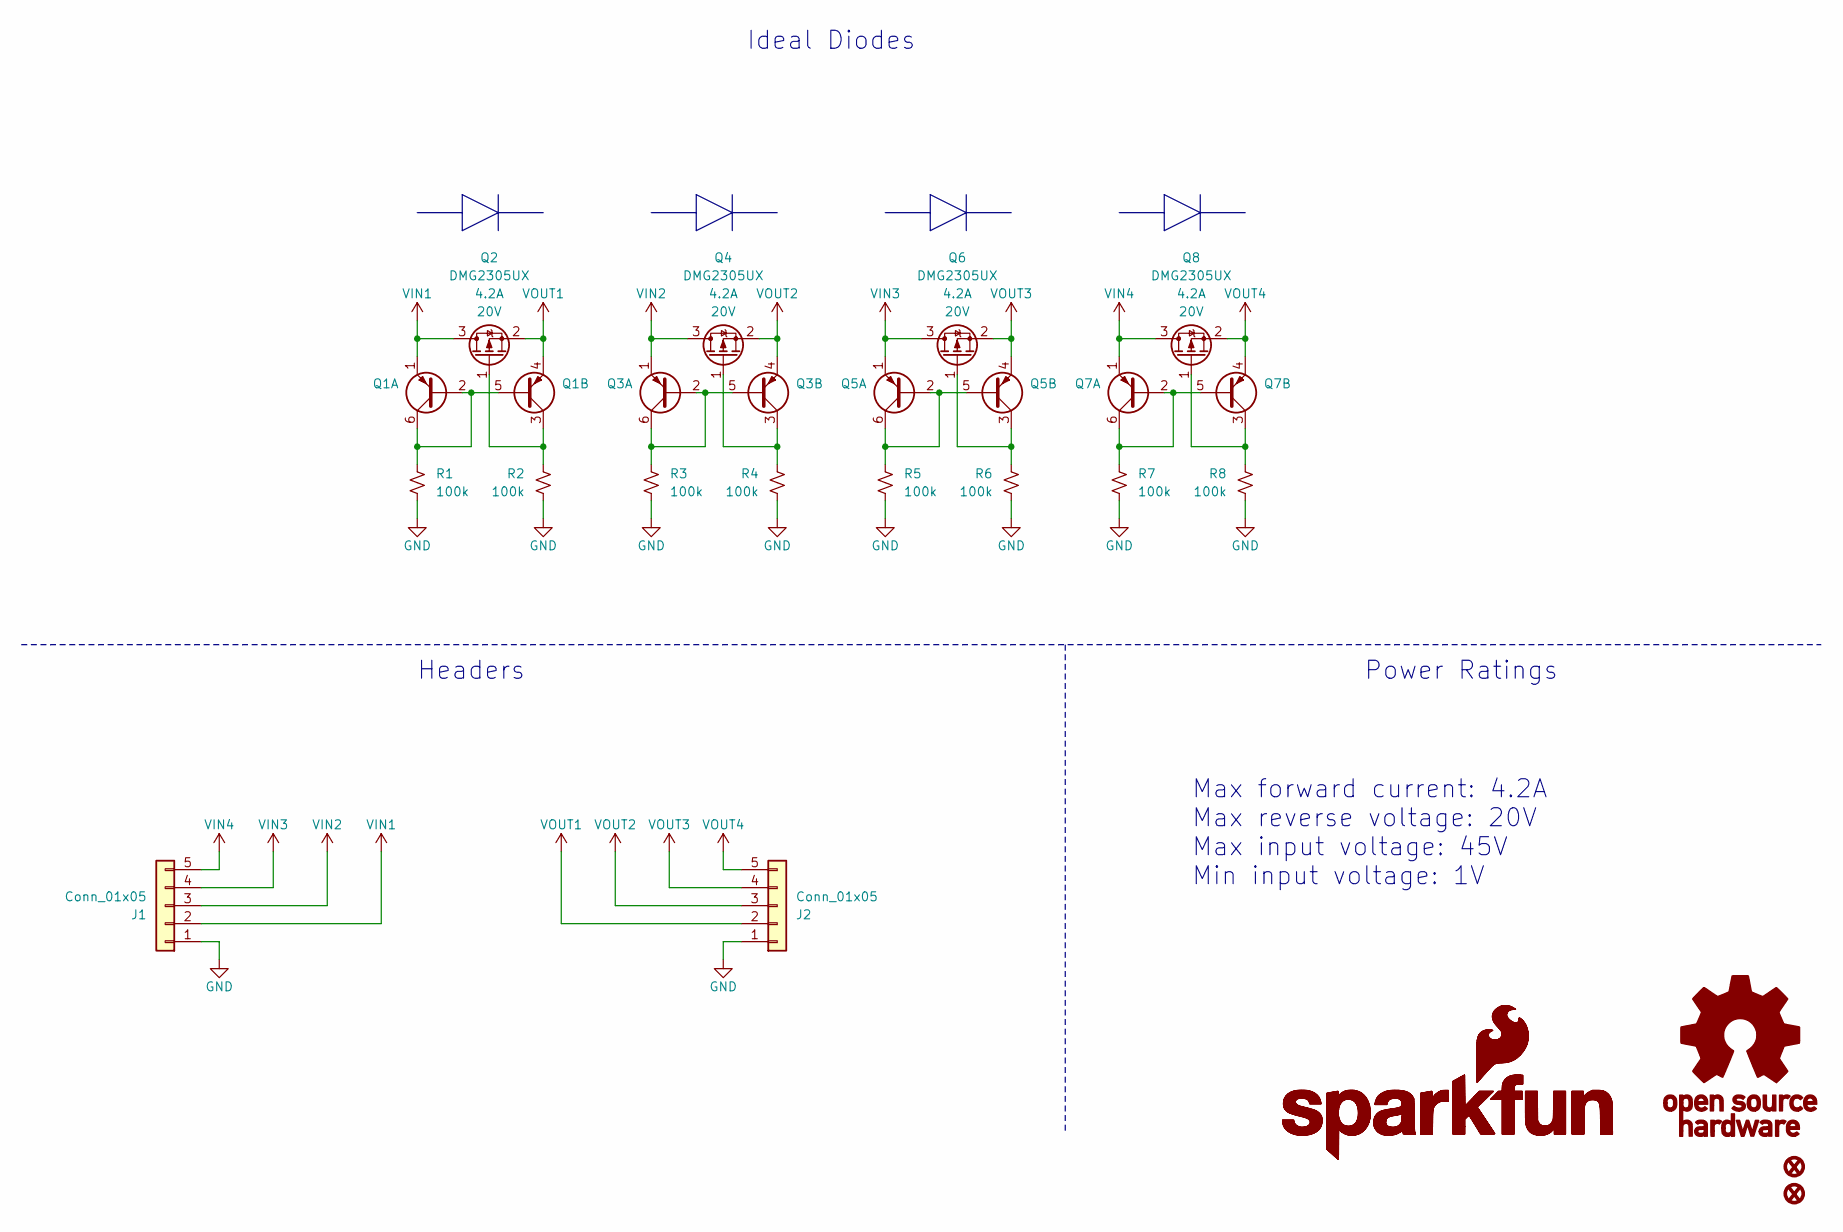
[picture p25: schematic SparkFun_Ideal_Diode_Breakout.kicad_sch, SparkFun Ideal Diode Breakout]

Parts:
FID1, FID4: Fiducial_0.5mm; Fiducial_0.5mm_Mask1mm
G1: SparkFun_Logo; SparkFun_Logo_8mm
G2: SparkFun_Logo
G3: OSHW_Logo; Creative_Commons_License
J1, J2: Conn_01x05; 1x05
Q1, Q3, Q5, Q7: BCM857BS-7-F; SOT-323
Q2, Q4, Q6, Q8: DMG2305UX; SOT23-3
R1, R2, R3, R4, R5, R6, R7, R8: 100k; R_0402_1005Metric

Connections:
GND: J1.1, J2.1, R1.1, R2.1, R3.1, R4.1, R5.1, R6.1, R7.1, R8.1
unnamed: Q1.2 (B), Q1.5 (B), Q1.6 (C), R1.2
unnamed: Q1.3 (C), Q2.1 (G), R2.2
unnamed: Q3.2 (B), Q3.5 (B), Q3.6 (C), R3.2
unnamed: Q3.3 (C), Q4.1 (G), R4.2
unnamed: Q5.2 (B), Q5.5 (B), Q5.6 (C), R5.2
unnamed: Q5.3 (C), Q6.1 (G), R6.2
unnamed: Q7.2 (B), Q7.5 (B), Q7.6 (C), R7.2
unnamed: Q7.3 (C), Q8.1 (G), R8.2
VIN1: J1.2, Q1.1 (E), Q2.3 (D)
VIN2: J1.3, Q3.1 (E), Q4.3 (D)
VIN3: J1.4, Q5.1 (E), Q6.3 (D)
VIN4: J1.5, Q7.1 (E), Q8.3 (D)
VOUT1: J2.2, Q1.4 (E), Q2.2 (S)
VOUT2: J2.3, Q3.4 (E), Q4.2 (S)
VOUT3: J2.4, Q5.4 (E), Q6.2 (S)
VOUT4: J2.5, Q7.4 (E), Q8.2 (S)

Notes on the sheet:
Max forward current: 4.2A Max reverse voltage: 20V Max input voltage: 45V Min input voltage: 1V
Headers
Power Ratings
Ideal Diodes

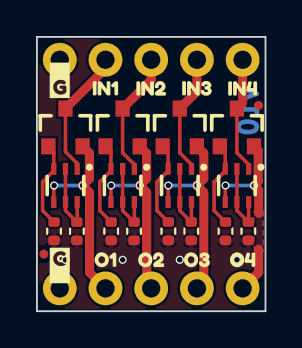
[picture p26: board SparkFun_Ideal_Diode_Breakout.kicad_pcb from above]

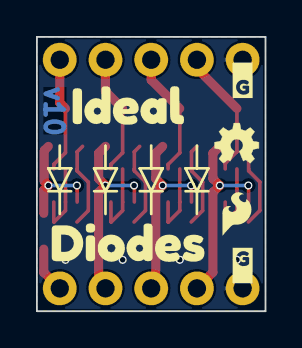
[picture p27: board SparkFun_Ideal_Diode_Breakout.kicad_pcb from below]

Board: 2 copper layers, 12.7 x 15.2 mm, 36 parts (5 on the bottom side), 17 nets.

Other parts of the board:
Ref**: Val**; OSHW_Logo_2.5mm
kibuzzard-6765BB94: G***; kibuzzard-6765BB94
kibuzzard-6765BBA3: G***; kibuzzard-6765BBA3
kibuzzard-6765D0F5: G***; kibuzzard-6765D0F5
kibuzzard-6765D0FB: G***; kibuzzard-6765D0FB
kibuzzard-6765D14E: G***; kibuzzard-6765D14E
kibuzzard-6765D15F: G***; kibuzzard-6765D15F
kibuzzard-6765D25C, kibuzzard-6765D25C#2: G***; kibuzzard-6765D25C
kibuzzard-6765D145: G***; kibuzzard-6765D145
kibuzzard-6765D154: G***; kibuzzard-6765D154
kibuzzard-6765D159: G***; kibuzzard-6765D159
kibuzzard-6765D166: G***; kibuzzard-6765D166
kibuzzard-6765D292, kibuzzard-6765D292#2: G***; kibuzzard-6765D292

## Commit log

2024-12-20 Add initial design
    [SparkFun_Ideal_Diode_Breakout.kicad_pcb, SparkFun_Ideal_Diode_Breakout.kicad_sch]
2024-12-20 Design review updates
    Update page info on schematic and board
    Separate schematic sections with lines and header text
    Add power ratings
    Add diode symbols to schematic
    Change GND symbol silk to "G"
    Check and exclude ERC and DRC errors
    Change top silk to "INx" and "Ox"
    Change GND silk to inverted text
    [SparkFun_Ideal_Diode_Breakout.kicad_pcb, SparkFun_Ideal_Diode_Breakout.kicad_sch]
2024-12-20 Change to 2 layer
    [SparkFun_Ideal_Diode_Breakout.kicad_pcb]
2025-01-31 Initial Pass of Documentation
    Not complete - just getting the bones in and what I have so far.
    [SparkFun_Ideal_Diode_Breakout.step, SparkFun_Ideal_Diode_Breakout_3d_model.step]
2025-02-04 Update ratings and add typical characteristics
    [SparkFun_Ideal_Diode_Breakout.kicad_sch]
2025-02-04 Testing build options and adding diode graphs
2025-07-08 Fix missing wire in hookup guide circuit
    Fixes #1

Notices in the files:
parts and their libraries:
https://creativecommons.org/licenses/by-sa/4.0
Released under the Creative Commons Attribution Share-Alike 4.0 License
